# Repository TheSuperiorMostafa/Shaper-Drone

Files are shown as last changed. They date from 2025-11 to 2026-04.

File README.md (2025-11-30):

# ShaperDrone - Autonomous Shape Navigation System

Software repository for the ShaperDrone Engineering Team's autonomous drone project.

## Repository Structure

### Beta 1 (`/beta1`)
Initial implementation with C++ shape detection and navigation modules.
- C++ navigation classes
- Xcode project files
- Drone simulation examples

### Beta 2 (`/beta2`)
Complete Python-based navigation system with full hardware integration.
- MAVLink integration for Flywoo GOKU GN745 V3 AIO flight controller
- Raspberry Pi camera support
- ToF sensor integration
- Autonomous navigation with visual servoing
- Complete setup documentation

## Quick Start

### Beta 2 (Recommended)
```bash
cd beta2
pip3 install opencv-python numpy pymavlink picamera2 VL53L0X
python3 shapeVideo.py
```

See `beta2/SETUP.md` for complete installation and hardware setup instructions.

## Project Overview

The ShaperDrone system enables autonomous navigation through a sequence of shapes. The drone learns a sequence of 3 shapes and then autonomously navigates to each one in order using computer vision and time-of-flight sensing.

## Team

ShaperDrone Engineering Team

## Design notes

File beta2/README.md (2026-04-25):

# ShaperDrone - Autonomous Shape Navigation System

Autonomous navigation system for a sub-250g drone that learns a sequence of shapes and navigates to them in order using computer vision and time-of-flight sensing.

## Hardware

- **Flight Controller:** Flywoo GOKU GN745 V3 AIO (ArduPilot firmware)
- **Computer:** Raspberry Pi Zero 2 W
- **Camera:** Raspberry Pi Camera Module
- **Sensors:** 
  - Time-of-Flight (ToF) sensor (VL53L0X or VL53L1X) for distance measurement
  - Optical Flow sensor (PMW3901, PX4Flow, or similar) for position/velocity estimation

## Features

- **Learning Phase:** Detects and stores 3 shapes in sequence with debouncing
- **Automatic Takeoff:** Automatically takes off to safe altitude after shape learning
- **Gate Navigation:** Flies through shaped gates (not just to them)
- **Navigation Phase:** Autonomously navigates through gates in learned order
- **Visual Servoing:** Uses camera feedback for precise navigation
- **Distance Control:** ToF sensor provides accurate distance measurements
- **Position Hold:** Optical flow sensor enables stable hovering and position hold
- **Velocity Estimation:** Optical flow provides velocity feedback for improved control
- **Motor Kill Switch:** Emergency stop immediately disarms motors (safety requirement)
- **Remote Manual Override:** Network interface for external emergency stop and control
- **Safety Features:** Timeouts, error recovery, automatic RTL

## Installation

See [SETUP.md](SETUP.md) for complete hardware and software setup instructions.

### Quick Start

```bash
# Install dependencies
pip3 install opencv-python numpy pymavlink picamera2 VL53L0X pmw3901

# Run the system
python3 shapeVideo.py
```

Note: For optical flow sensor, install `pmw3901` for PMW3901 sensor or configure for your specific sensor type.

## Controls

### Local Keyboard Controls
- **'q' or ESC:** Quit program
- **'r':** Reset shape order
- **'n':** Manually start navigation
- **'s':** Emergency stop (local)

### Remote Control (Network)
The system includes a remote control server on port 8888 for external manual override:
- **Emergency Stop:** `python3 remote_client.py <pi_ip> emergency_stop`
- **Status Check:** `python3 remote_client.py <pi_ip> status`
- **Telnet:** `telnet <pi_ip> 8888` then type `emergency_stop` or `status`

The remote emergency stop immediately disarms motors (motor kill switch) for safety.

## Project Structure

- `shapeVideo.py` - Main program with camera, shape detection, and navigation
- `navigation.py` - MAVLink flight controller communication (includes takeoff, emergency disarm)
- `shape_navigator.py` - Navigation state machine with gate navigation and visual servoing
- `test_hover.py` - Program testing final prototype integration between navigation and flight controller
- `tof_sensor.py` - Time-of-flight sensor interface
- `optical_flow.py` - Optical flow sensor interface for position/velocity estimation
- `remote_control.py` - Remote control server for manual override and emergency stop
- `remote_client.py` - Client script for remote control commands
- `SETUP.md` - Complete setup guide

## License

[Add your license here]

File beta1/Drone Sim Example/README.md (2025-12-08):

# Drone Simulator Example Script
This is a simple script which shows how a simulated Ardupilot drone can be controlled through a Python script using pymavlink.

## Usage

### Prerequisites
Before you can use this script, you must first install an [Ardupilot Simulator](https://ardupilot.org/dev/docs/simulation-2.html). 
I highly recommend [Mission Planner](https://ardupilot.org/planner/docs/mission-planner-overview.html) for this if you're on a Windows machine, but the [SITL simulator](https://ardupilot.org/dev/docs/sitl-simulator-software-in-the-loop.html#sitl-simulator-software-in-the-loop) is also an option.

You will also need Python 3 and the [pymavlink](https://pypi.org/project/pymavlink/) library.

### Starting the simulator (Mission Planner)
This script uses TCP on port 5764 to communicate with Mission Planner's SITL instance, so you will need to set up Mavlink mirroring before starting the simulator in Mission Planner. See the image below. 
**Note, you will need to click the go/started button here every time you restart mission planner**, otherwise the Python script will be unable to connect.

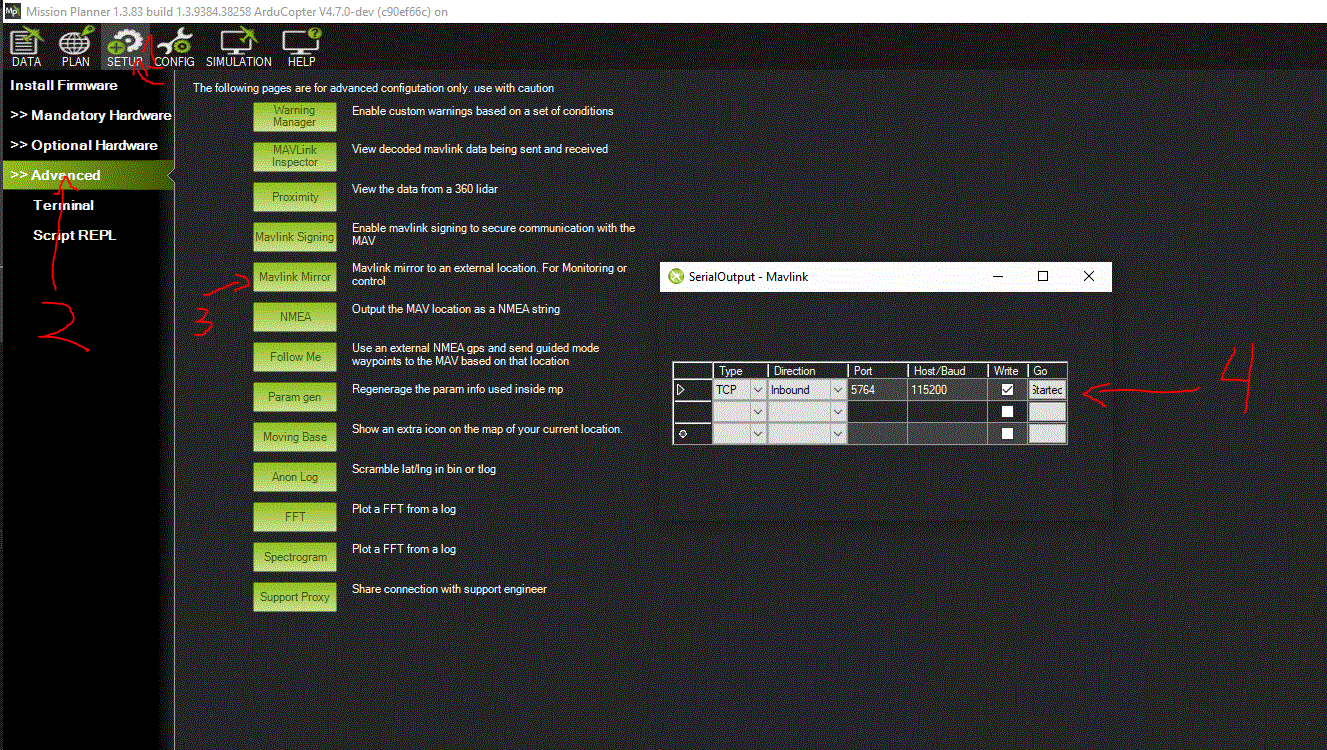
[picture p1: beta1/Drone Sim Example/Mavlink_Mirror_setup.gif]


After this, click on the Simulation tab at the top of the window, and then click the multirotor button at the bottom. The simulation should start.

### Running the script
After the simulation is running, simply run the Python script. The drone should start moving around on its own.

## Useful Guides
Here are some guides that might be useful if you want to familiarize yourself with Ardupilot's simulator, pymavlink, and the Mavlink protocol in general.
- [Mission Planner Simulator user guide](https://www.youtube.com/watch?v=gnSbaGDzrHE): Simple tutorial which is really helpful if you haven't Mission Planner's simulator before.
- [Introduction to pymavlink playlist](https://www.youtube.com/watch?v=kecnaxlUiTY&list=PLy9nLDKxDN68cwdt5EznyAul6R8mUSNou): Good video series to familiarize yourself with using pymavlink.
- [Text based guide on getting started with pymavlink](https://mavlink.io/en/mavgen_python/)

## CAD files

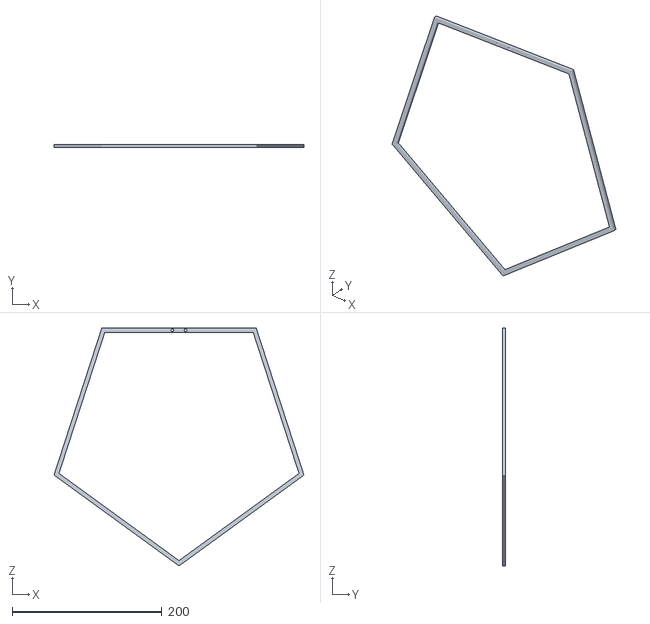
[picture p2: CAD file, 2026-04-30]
3D files/Course/PentagonGate.STL
333.8 x 3.81 x 317.5

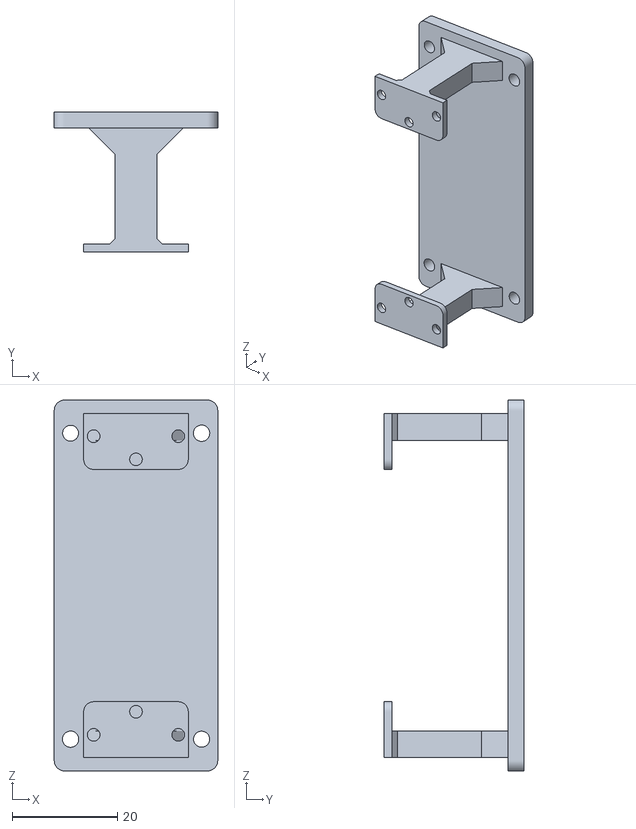
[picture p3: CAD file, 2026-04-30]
3D files/Drone/.STL Files/PI MOUNT 02-08-26.STL
31.0 x 26.5 x 70.4

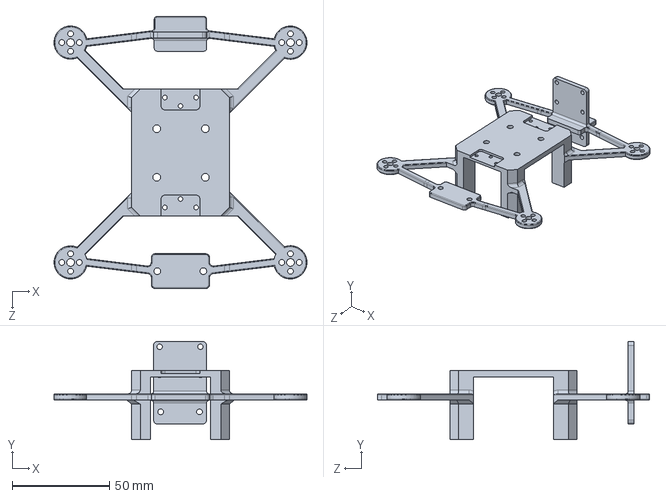
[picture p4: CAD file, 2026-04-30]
3D files/Drone/SolidWorks Files/FRAME RE DO 4-12-26 IN PROG.SLDPRT
130.3 x 50.5 x 140.2 mm

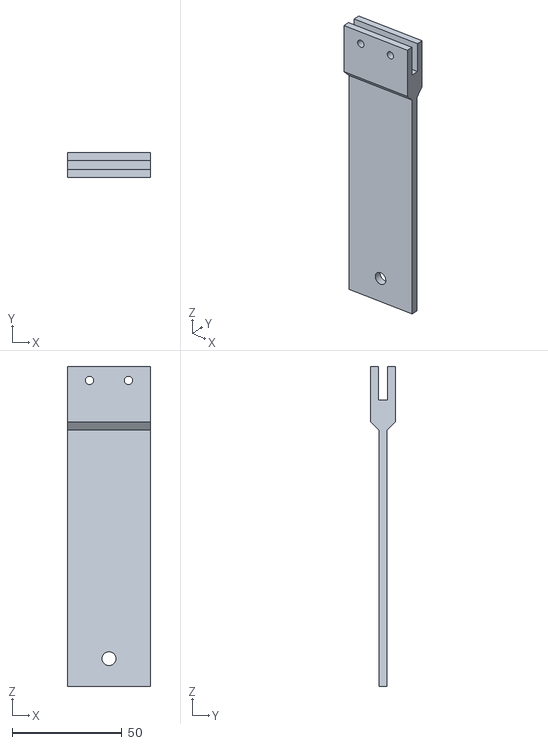
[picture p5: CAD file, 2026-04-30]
3D files/Course/GateToPVCAttachment.STL
38.1 x 11.4 x 146.1

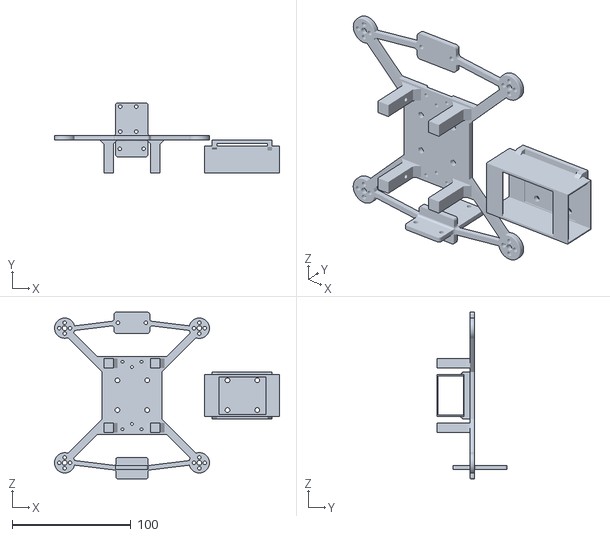
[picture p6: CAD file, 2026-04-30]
3D files/Drone/.STL Files/FRAME + BATTERY STACK 1-28-26.STL
189.2 x 59.2 x 140.2

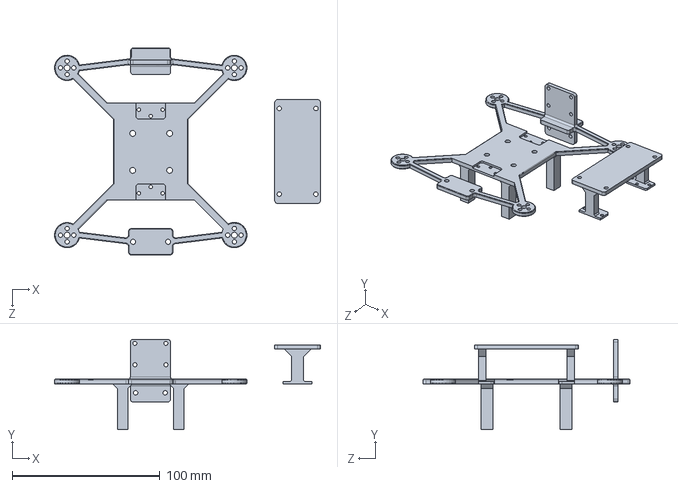
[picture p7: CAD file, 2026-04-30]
3D files/Drone/SolidWorks Files/done and mount 3-30-26.SLDPRT
180.1 x 61.2 x 140.2 mm

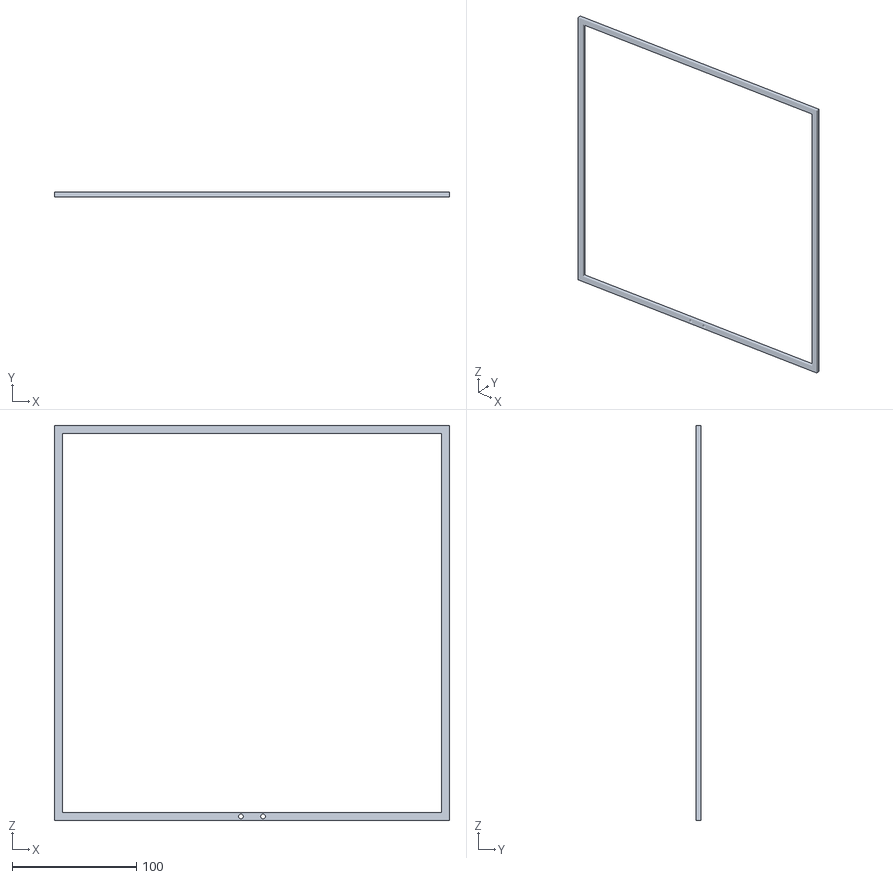
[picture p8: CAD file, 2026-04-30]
3D files/Course/SquareGate.STL
317.5 x 3.81 x 317.5

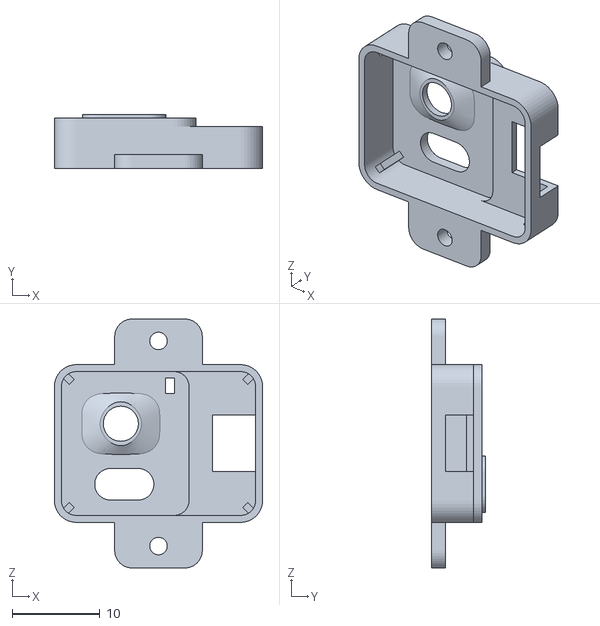
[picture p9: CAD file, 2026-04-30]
3D files/Drone/.STL Files/MTF-02P-V1.2 case.wmounting2.STL
23.8 x 6.20 x 28.4

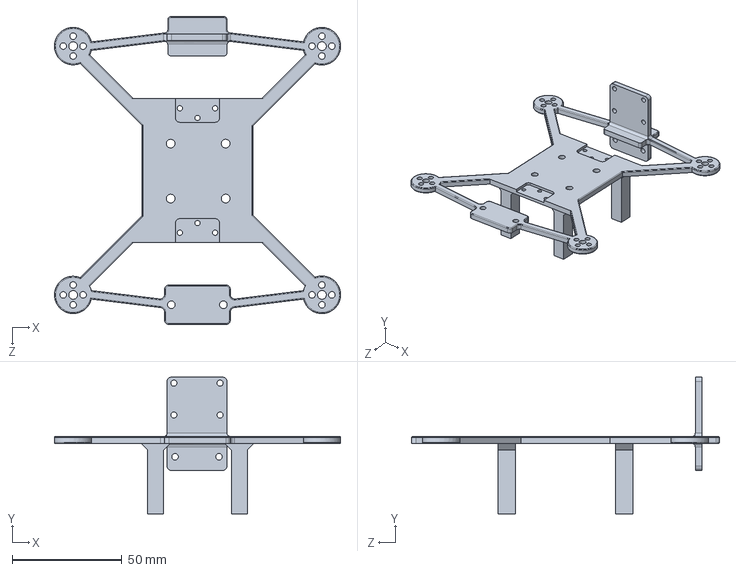
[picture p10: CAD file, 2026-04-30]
3D files/Drone/SolidWorks Files/Frame only 4-2-26.SLDPRT
130.3 x 62.2 x 140.2 mm

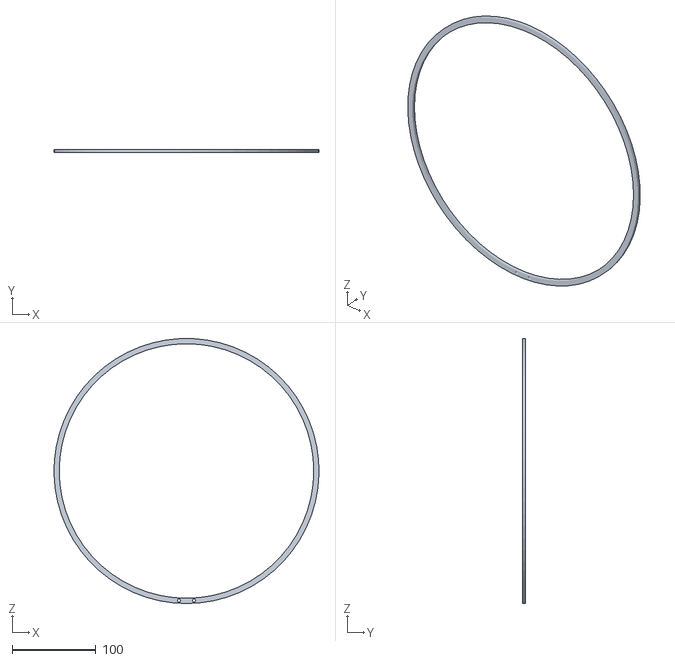
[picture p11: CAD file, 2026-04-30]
3D files/Course/CircleGate.STL
317.4 x 3.81 x 317.5

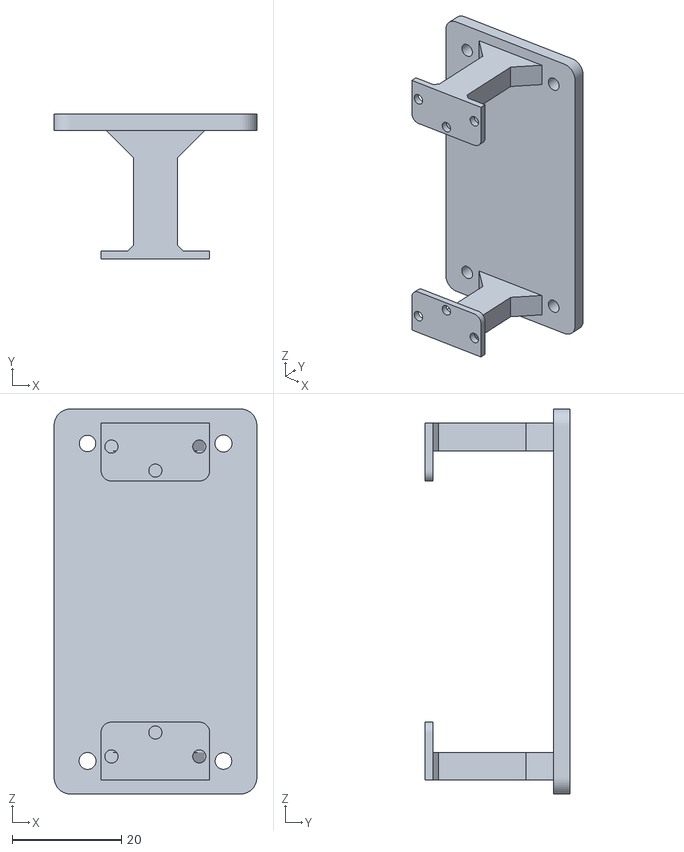
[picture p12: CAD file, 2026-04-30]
3D files/Drone/.STL Files/PI MOUNT v2 STL.STL
37.1 x 26.5 x 70.4

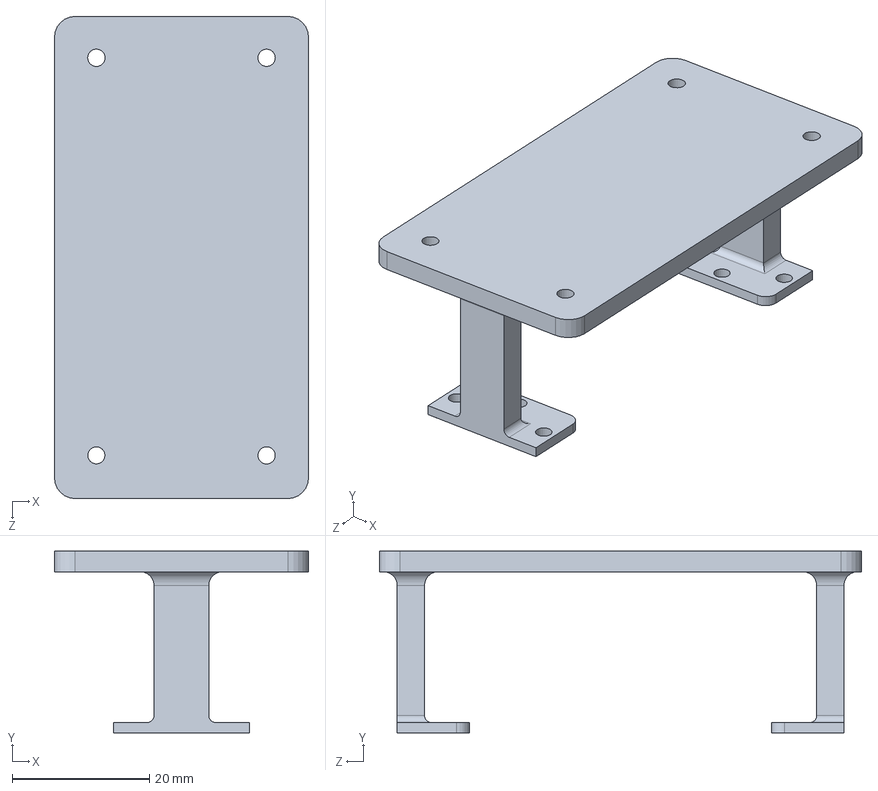
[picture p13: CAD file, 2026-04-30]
3D files/Drone/SolidWorks Files/DRONE FRAME - MODULAR 1-20-26.SLDPRT
37.1 x 26.5 x 70.4 mm

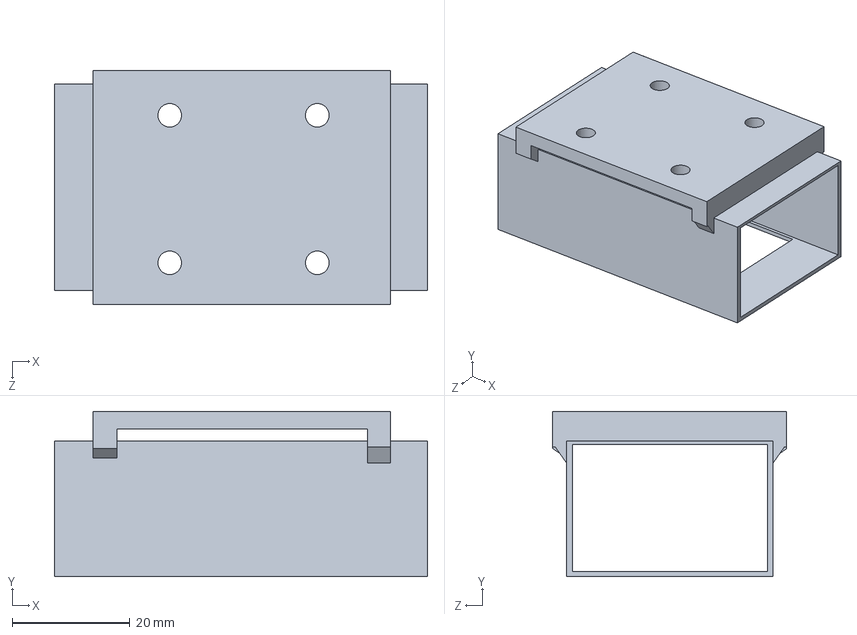
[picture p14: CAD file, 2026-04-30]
3D files/Drone/SolidWorks Files/batt pack 4-2-26.SLDPRT
63.3 x 28.0 x 39.7 mm

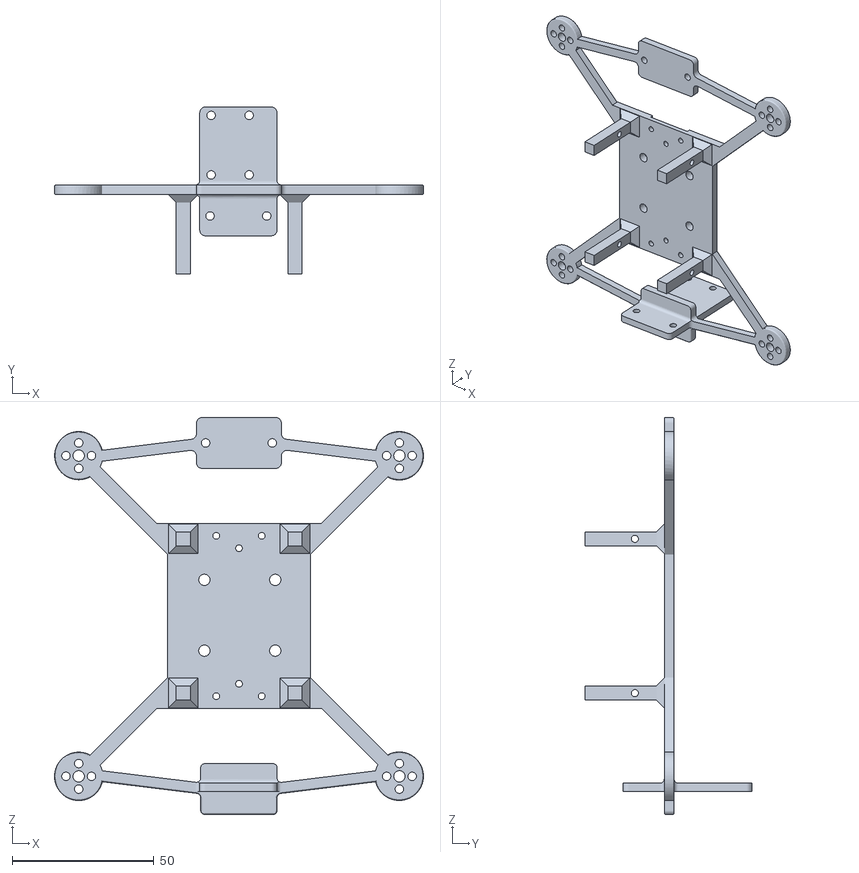
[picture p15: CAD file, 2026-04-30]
3D files/Drone/.STL Files/drone 1-26-26.STL
130.3 x 59.0 x 140.2

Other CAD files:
3D files/Drone/.STL Files/FRAME RE DO 4-12-26.STL
3D files/Drone/SolidWorks Files/PI MOUNT 1-20-26.SLDPRT
3D files/Drone/.STL Files/pi mount 4-2-26.STL
3D files/Drone/SolidWorks Files/FRAME RE DO 4-19-26 IN PROG.SLDPRT
3D files/Drone/.STL Files/DRONE FRAME WITH PI MOUNT - MODULAR 1-21-26.STL
3D files/Drone/.STL Files/DRONE FRAME - MODULAR 1-20-26.STL
3D files/Drone/.STL Files/FRAME RE DO 4-19-26 IN PROG.STL
3D files/Drone/.STL Files/Frame only 4-2-26.STL
3D files/Drone/.STL Files/PI MOUNT 1-20-26.STL
3D files/Drone/.STL Files/batt pack 4-2-26.STL
3D files/Drone/.STL Files/frame only 3-30-26.STL
3D files/Drone/.STL Files/mount only 3-30-26.STL
3D files/Drone/SolidWorks Files/PI MOUNT 02-08-26.SLDDRW

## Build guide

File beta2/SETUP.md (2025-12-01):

# ShaperDrone Setup Guide

## Hardware Components

- **Flight Controller:** Flywoo GOKU GN745 V3 AIO (ArduPilot firmware)
- **Computer:** Raspberry Pi Zero 2 W
- **Camera:** Raspberry Pi Camera Module
- **Sensor:** Time-of-Flight (ToF) sensor (VL53L0X or VL53L1X)

## Hardware Connections

### Flight Controller to Raspberry Pi

1. **UART Connection:**
   - Connect Raspberry Pi GPIO 14 (TX) → FC UART RX
   - Connect Raspberry Pi GPIO 15 (RX) → FC UART TX
   - Connect Ground (GND) → FC GND
   
2. **Power:**
   - Flywoo GOKU GN745 V3 has 5V/2A BEC output
   - Can power Raspberry Pi Zero 2 W (requires ~1A)
   - Connect FC 5V BEC → Pi 5V
   - Connect FC GND → Pi GND

### Camera Connection

- Connect Raspberry Pi Camera Module to Pi's camera connector (CSI)

### ToF Sensor Connections

**Forward-Facing ToF Sensor (for distance to shapes/gates):**
- Connect ToF sensor (VL53L0X) to Raspberry Pi I2C bus:
  - VCC → Pi 3.3V
  - GND → Pi GND
  - SDA → Pi GPIO 2 (I2C SDA)
  - SCL → Pi GPIO 3 (I2C SCL)
- Mount: Point forward, toward shapes/gates
- Purpose: Measures horizontal distance to shapes/gates

**Downward-Facing ToF Sensor (for altitude):**
- Connect second ToF sensor (VL53L0X) to Raspberry Pi I2C bus:
  - VCC → Pi 3.3V
  - GND → Pi GND
  - SDA → Pi GPIO 2 (I2C SDA) - can share same bus
  - SCL → Pi GPIO 3 (I2C SCL) - can share same bus
- **Important:** If using two VL53L0X sensors, you need to change one's I2C address
  - Default VL53L0X address: 0x29
  - Change one sensor's address to 0x30 (or another available address)
  - Or use one VL53L0X and one VL53L1X (they have different default addresses)
- Mount: Point downward, toward ground
- Purpose: Measures altitude (height above ground)

### Optical Flow Sensor Connection (MTF-02B)

- Connect MTF-02B to Raspberry Pi I2C bus:
  - VCC → Pi 3.3V (or 5V, check sensor specifications)
  - GND → Pi GND
  - SDA → Pi GPIO 2 (I2C SDA)
  - SCL → Pi GPIO 3 (I2C SCL)
- Default I2C address: 0x42
- Note: Both ToF and Optical Flow sensors can share the same I2C bus

## ArduPilot Configuration

### 1. Flash ArduPilot Firmware

- Use Mission Planner or QGroundControl to flash ArduPilot firmware
- Select appropriate frame type (Quad, Hex, etc.)

### 2. Configure Serial Port for MAVLink

In Mission Planner or via CLI:

```
SERIALx_PROTOCOL = 2    # MAVLink protocol
SERIALx_BAUD = 57       # 57600 baud
```

Where `x` is the UART port number you're using (typically 1, 2, or 3).

### 3. Enable GUIDED Mode

GUIDED mode should be available by default in ArduPilot. Verify in Mission Planner:
- Flight Modes → GUIDED should be enabled

### 4. Calibration

Complete standard ArduPilot calibration:
- Accelerometer calibration
- Compass calibration
- Radio calibration
- ESC calibration

## Raspberry Pi Setup

### 1. Enable Interfaces

```bash
sudo raspi-config
```

Enable:
- Camera
- I2C
- Serial Port (disable login shell, enable serial port)

### 2. Install Dependencies

```bash
# Update system
sudo apt update && sudo apt upgrade -y

# Install Python packages
pip3 install opencv-python numpy pymavlink picamera2

# For ToF sensor (VL53L0X)
pip3 install VL53L0X

# Or for VL53L1X
pip3 install VL53L1X

# For Optical Flow sensor
# MTF-02B uses smbus (usually pre-installed, or install with: pip3 install smbus2)
# For PMW3901: pip3 install pmw3901
```

### 3. Serial Port Permissions

Add user to dialout group:
```bash
sudo usermod -a -G dialout $USER
```

Log out and back in for changes to take effect.

### 4. Test Serial Connection

```bash
# Check if serial port is available
ls -l /dev/ttyAMA0

# Test connection (optional)
python3 -c "from pymavlink import mavutil; conn = mavutil.mavlink_connection('/dev/ttyAMA0', baud=57600); conn.wait_heartbeat(); print('Connected!')"
```

## Software Configuration

### 1. Configure Sensor Types

Edit `shapeVideo.py`, line ~237-248:
```python
# Forward-facing ToF for distance to shapes/gates
tof_forward = TOFSensor(sensor_type='VL53L0X', i2c_bus=1, address=None)

# Downward-facing ToF for altitude
tof_altitude = TOFSensor(sensor_type='VL53L0X', i2c_bus=1, address=None)
# Note: If both are VL53L0X, configure different I2C addresses
# Or use one VL53L0X and one VL53L1X
```

Edit `shapeVideo.py`, line ~242:
```python
optical_flow = OpticalFlowSensor(sensor_type='MTF-02B', interface='I2C', bus=1, device=0x42)
# MTF-02B is the default. Change to 'PMW3901', 'PX4Flow', or 'simulated' as needed
```

### 2. Adjust Navigation Parameters (Optional)

Edit `shape_navigator.py` to adjust:
- `approach_distance`: Target distance from shapes (default: 2.0m)
- `max_velocity`: Maximum flight velocity (default: 1.0 m/s)
- `search_timeout`: Time to search for each shape (default: 30s)

## Running the System

### 1. Start the Program

```bash
python3 shapeVideo.py
```

### 2. Learning Phase

- Show the drone 3 shapes in sequence
- System will learn the order automatically
- Wait for "ORDER LOCKED" message

### 3. Navigation Phase

- Navigation starts automatically when order is complete
- Or press 'n' to start manually
- Drone will navigate to each shape in sequence

### 4. Controls

- **'q' or ESC:** Quit program
- **'r':** Reset shape order
- **'n':** Manually start navigation
- **'s':** Emergency stop

## Troubleshooting

### Flight Controller Not Connecting

1. Check UART wiring (TX→RX, RX→TX, GND)
2. Verify ArduPilot SERIALx_PROTOCOL = 2
3. Check baud rate matches (57600)
4. Verify serial port permissions
5. Try different UART ports on FC

### Camera Not Working

1. Verify camera is connected to CSI port
2. Enable camera in raspi-config
3. Test with: `libcamera-hello -t 0`

### ToF Sensor Not Detected

1. Check I2C wiring
2. Enable I2C in raspi-config
3. Scan for device: `i2cdetect -y 1`
4. Verify sensor library is installed

### Optical Flow Sensor (MTF-02B) Not Detected

1. **Check I2C wiring:**
   - Verify SDA and SCL connections
   - Ensure proper power (3.3V or 5V depending on sensor)
   - Check ground connection

2. **Enable I2C:**
   - Enable I2C in raspi-config
   - Reboot if necessary

3. **Verify sensor detection:**
   - Scan for device: `i2cdetect -y 1`
   - MTF-02B should appear at address 0x42
   - If not detected, check wiring and power

4. **Check sensor requirements:**
   - Ensure sensor has good lighting
   - Optical flow requires textured surface to work properly
   - Check sensor height (should be 0.5-4m for best results)
   - Sensor should be pointing downward

5. **For other sensors:**
   - **PMW3901 (SPI):** Check SPI wiring, enable SPI, verify library installed
   - **PX4Flow (I2C):** Similar to MTF-02B, check I2C address

### Navigation Issues

1. Ensure shapes are well-lit and high contrast
2. Adjust shape detection thresholds in `shapeVideo.py`
3. Check ToF sensor is providing valid readings
4. Verify flight controller is in GUIDED mode

## Safety Notes

- Always test in a safe, open area
- Start with low velocities
- Have emergency stop ready
- Verify RTL (Return to Launch) works before autonomous flight
- Check battery levels before flight
- Follow local drone regulations

## Specifications Reference

**Flywoo GOKU GN745 V3 AIO:**
- Processor: STM32F745 @ 216MHz
- UART Ports: 7 available
- BEC: 5V/2A (can power Pi Zero 2 W)
- Firmware: ArduPilot compatible

**Raspberry Pi Zero 2 W:**
- Processor: BCM2710A1 (Quad-core 64-bit)
- GPIO UART: /dev/ttyAMA0 (GPIO 14/15)
- I2C: GPIO 2 (SDA), GPIO 3 (SCL)
- Camera: CSI connector

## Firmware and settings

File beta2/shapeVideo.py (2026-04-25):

# shapeVideo.py
# Transitioning from static images to video shape detection

import os
import sys

# Set OpenCV to use a backend that doesn't require X11 (for headless operation)
if 'DISPLAY' not in os.environ:
    os.environ['QT_QPA_PLATFORM'] = 'offscreen'
    # Try to set OpenCV backend to avoid Qt issues
    try:
        os.environ['OPENCV_VIDEOIO_PRIORITY_MSMF'] = '0'
    except:
        pass

import cv2
import time
import numpy as np
import threading
import socket
import struct
from queue import Queue, Empty
from http.server import BaseHTTPRequestHandler, HTTPServer
from navigation import FlightController
from shape_navigator import ShapeNavigator
from remote_control import RemoteControl

try:
    from tof_sensor import TOFSensor
except ModuleNotFoundError:
    class TOFSensor:
        def __init__(self, *args, **kwargs):
            pass
        def is_connected(self):
            return False
        def read_distance(self):
            return None
        def close(self):
            pass

# Vision-only mode: skip flight controller connection (for standalone Pi vision testing)
# Set to True when testing camera/shape detection without FC connected; False when flying.
VISION_ONLY = True

# Check if running headless (no display)
HEADLESS_MODE = 'DISPLAY' not in os.environ
if HEADLESS_MODE:
    print("[INFO] Running in headless mode (no display available)")

# Debug flag for verbose shape-order debounce logging
DEBUG_DEBOUNCE = False

# Stream / processing latency
# - LOW_RES: 320x240 (faster but text/order gets cut off; set False for readable overlays)
# - PROCESS_LATEST_ONLY: skip backlog, always process/display newest frame (reduces delay)
# - PROCESS_EVERY_N_FRAMES: only process every Nth frame (2 = process every 2nd frame, reduces CPU load)
# - ENABLE_HTTP_STREAM: enable HTTP streaming server (disable to reduce CPU/network overhead)
# - ENABLE_UDP_STREAM: enable UDP streaming (lower latency than HTTP)
# - UDP_TARGET_IP: laptop/viewer IP for unicast (e.g. '10.47.232.91'). Set None for broadcast (may not work on eduroam)
LOW_RES_STREAM = False  # 640x480 so full order and labels fit on screen
PROCESS_LATEST_ONLY = True
PROCESS_EVERY_N_FRAMES = 1  # Process every 2nd frame to reduce CPU load
ENABLE_HTTP_STREAM = False  # Set False to disable HTTP streaming and reduce lag
ENABLE_UDP_STREAM = True  # Set True to enable UDP streaming
UDP_TARGET_IP = '10.47.104.64'  # Set to your laptop IP (e.g. '10.47.232.91') for unicast; None = broadcast

# Try to import picamera2 for Raspberry Pi camera
try:
    from picamera2 import Picamera2
    PICAMERA2_AVAILABLE = True
except ImportError:
    PICAMERA2_AVAILABLE = False
    print("[INFO] picamera2 not available, will use OpenCV VideoCapture (USB camera)")


shape_order = []      # will hold up to 3 unique shapes, e.g. ["triangle", "square", "circle"]
order_complete = False

# Debounce state
current_candidate = None
candidate_start_time = None
DEBOUNCE_SECONDS = 1.5  # require ~3s of stable viewing to add a shape to the array

# Global variable to hold the latest frame for streaming
latest_frame = None
frame_lock = threading.Lock()

# Thread-safe queues for frame processing pipeline
# Smaller queues (1-2) reduce latency by preventing frame accumulation
# Frames are dropped if processing can't keep up, ensuring stream shows recent frames
raw_frame_queue = Queue(maxsize=1)  # Raw frames from camera - keep small for low latency
processed_frame_queue = Queue(maxsize=1)  # Processed frames - keep small for low latency
shutdown_event = threading.Event()  # Signal to stop all threads

# Set by stdin listener thread when user types in terminal (headless)
reset_from_stdin_event = threading.Event()
stop_from_stdin_event = threading.Event()

class StreamingHandler(BaseHTTPRequestHandler):
    def do_GET(self):
        if self.path == '/stream':
            self.send_response(200)
            self.send_header('Content-Type', 'multipart/x-mixed-replace; boundary=frame')
            self.end_headers()
            while True:
                with frame_lock:
                    if latest_frame is not None:
                        # Encode frame as JPEG - lower quality (55) for faster encoding and smaller files
                        # This improves stream responsiveness on slower hardware
                        ret, buffer = cv2.imencode('.jpg', latest_frame, [cv2.IMWRITE_JPEG_QUALITY, 55])
                        if ret:
                            frame_bytes = buffer.tobytes()
                            self.wfile.write(b'--frame\r\n')
                            self.send_header('Content-Type', 'image/jpeg')
                            self.send_header('Content-Length', str(len(frame_bytes)))
                            self.end_headers()
                            self.wfile.write(frame_bytes)
                            self.wfile.write(b'\r\n')
                # Reduced sleep for higher frame rate - actual rate limited by camera + processing
                # If processing is slow, we'll show frames as fast as they're available
                time.sleep(0.01)
        elif self.path == '/' or self.path == '/index.html':
            self.send_response(200)
            self.send_header('Content-Type', 'text/html')
            self.end_headers()
            self.wfile.write(b'''
<!DOCTYPE html>
<html>
<head>
    <title>ShaperDrone Camera Stream</title>
    <style>
        body { margin: 0; background: #000; text-align: center; }
        img { max-width: 100%; height: auto; }
    </style>
</head>
<body>
    <img src="/stream" alt="Camera Stream">
</body>
</html>
            ''')
        else:
            self.send_error(404)

def start_streaming_server(port=8080):
    """Start HTTP server for MJPEG streaming"""
    server = HTTPServer(('0.0.0.0', port), StreamingHandler)
    server_thread = threading.Thread(target=server.serve_forever, daemon=True)
    server_thread.start()
    print(f"[STREAM] Camera stream available at http://<pi_ip>:{port}/stream")
    print(f"[STREAM] Web viewer at http://<pi_ip>:{port}/")
    return server

def udp_stream_thread(port=8081, shutdown_event=None, target_ip=None):
    """
    UDP streaming thread - sends JPEG frames over UDP for lower latency.
    target_ip: send to this IP (unicast). If None, use broadcast (may not work on eduroam).
    View with: python udp_viewer.py
    """
    sock = socket.socket(socket.AF_INET, socket.SOCK_DGRAM)
    if target_ip:
        dest = (target_ip, port)
        print(f"[UDP] UDP stream started, sending to {target_ip}:{port} (unicast)")
    else:
        sock.setsockopt(socket.SOL_SOCKET, socket.SO_BROADCAST, 1)
        dest = ('255.255.255.255', port)
        print(f"[UDP] UDP stream started on port {port} (broadcast)")
    print(f"[UDP] Run: python udp_viewer.py (on the viewer machine)")
    
    while not shutdown_event.is_set():
        try:
            with frame_lock:
                if latest_frame is not None:
                    # Encode frame as JPEG (same quality as HTTP stream)
                    ret, buffer = cv2.imencode('.jpg', latest_frame, [cv2.IMWRITE_JPEG_QUALITY, 55])
                    if ret:
                        frame_bytes = buffer.tobytes()
                        frame_size = len(frame_bytes)
                        
                        # Send frame size (4 bytes) + frame data
                        # Format: [4-byte size][JPEG data]
                        packet = struct.pack('>I', frame_size) + frame_bytes
                        
                        try:
                            sock.sendto(packet, dest)
                        except OSError:
                            if not target_ip:
                                try:
                                    sock.sendto(packet, ('127.0.0.1', port))
                                except OSError:
                                    pass
            
            # Small sleep to avoid hammering the network
            time.sleep(0.01)
        except Exception as e:
            print(f"[UDP] Stream error: {e}")
            time.sleep(0.1)
    
    sock.close()
    print("[UDP] UDP stream stopped")

def frame_capture_thread(camera, use_picamera, raw_frame_queue, shutdown_event):
    """
    Thread function to continuously capture frames from camera.
    Runs independently to prevent blocking the main loop.
    """
    print("[THREAD] Frame capture thread started")
    consecutive_errors = 0
    max_errors = 5
    
    while not shutdown_event.is_set():
        try:
            # Read frame from camera
            if use_picamera:
                frame = camera.capture_array()
                # picamera2 returns RGB, convert to BGR for OpenCV
                frame = cv2.cvtColor(frame, cv2.COLOR_RGB2BGR)
                frame = cv2.rotate(frame, cv2.ROTATE_180)
            else:
                ret, frame = camera.read()
                if not ret:
                    consecutive_errors += 1
                    if consecutive_errors >= max_errors:
                        print("[THREAD] Frame capture thread: too many read errors, stopping")
                        break
                    time.sleep(0.1)
                    continue
            
            consecutive_errors = 0
            
            # Put frame in queue for processing (non-blocking, drop old frames if queue is full)
            try:
                raw_frame_queue.put_nowait(frame)
            except:
                # Queue is full, drop oldest frame and add new one
                try:
                    raw_frame_queue.get_nowait()
                    raw_frame_queue.put_nowait(frame)
                except:
                    pass
            
        except Exception as e:
            print(f"[THREAD] Frame capture error: {e}")
            time.sleep(0.1)
    
    print("[THREAD] Frame capture thread stopped")

def frame_processing_thread(raw_frame_queue, processed_frame_queue, tof_sensor, shutdown_event, min_contour_area=800):
    """
    Thread function to process frames for shape detection.
    Runs independently to prevent blocking frame capture or navigation.
    min_contour_area: minimum contour area (e.g. 200 for 320x240, 800 for 640x480).
    """
    print("[THREAD] Frame processing thread started")
    
    # Frame skipping counter for PROCESS_EVERY_N_FRAMES
    frame_counter = 0
    last_result = None  # Store last processed result to reuse when skipping frames
    
    while not shutdown_event.is_set():
        try:
            # Get frame(s) from queue
            frame = None
            if PROCESS_LATEST_ONLY:
                # Drain queue and keep only the latest frame (reduces delay from backlog)
                while True:
                    try:
                        frame = raw_frame_queue.get_nowait()
                    except Empty:
                        break
            if frame is None:
                try:
                    frame = raw_frame_queue.get(timeout=0.05)
                except Empty:
                    continue
            
            # Frame skipping: only process every Nth frame to reduce CPU load
            frame_counter += 1
            if frame_counter % PROCESS_EVERY_N_FRAMES != 0:
                # Skip processing - reuse last result if available, or pass raw frame
                if last_result is not None:
                    # Reuse last processed result (labels/positions stay same, but update frame for visual continuity)
                    result = last_result.copy()
                    result['frame'] = frame  # Use current raw frame so stream stays responsive
                    try:
                        processed_frame_queue.put_nowait(result)
                    except:
                        try:
                            processed_frame_queue.get_nowait()
                            processed_frame_queue.put_nowait(result)
                        except:
                            pass
                continue
            
            # Read ToF sensor distance
            distance = tof_sensor.read_distance()
            
            # Process frame for shape detection
            annotated, frame_labels, shape_positions = process_frame(frame, min_contour_area)
            
            # Store result for reuse when skipping frames
            last_result = {
                'frame': annotated,
                'labels': frame_labels,
                'positions': shape_positions,
                'distance': distance
            }
            
            # Put processed result in queue
            try:
                processed_frame_queue.put_nowait(last_result)
            except:
                # Queue is full, drop oldest result and add new one
                try:
                    processed_frame_queue.get_nowait()
                    processed_frame_queue.put_nowait(last_result)
                except:
                    pass
                    
        except Exception as e:
            print(f"[THREAD] Frame processing error: {e}")
            time.sleep(0.01)
    
    print("[THREAD] Frame processing thread stopped")

def stdin_listener_thread(shutdown_evt, reset_evt, stop_evt):
    """
    Read lines from terminal stdin; set reset_evt for 'r'/'reset', stop_evt for 's'/'stop'.
    Allows reset and emergency stop from the SSH terminal when running headless.
    """
    while not shutdown_evt.is_set():
        try:
            line = sys.stdin.readline()
            if not line:
                break
            s = line.strip().lower()
            if s in ('r', 'reset'):
                reset_evt.set()
            elif s in ('s', 'stop'):
                stop_evt.set()
        except Exception:
            break
    print("[THREAD] Stdin listener stopped")

def classify(contour, min_area=800):
    area = cv2.contourArea(contour)

    if area < min_area:
        return None

    perim = cv2.arcLength(contour, True)
    if perim == 0:
        return None

    circularity = 4.0 * np.pi * area / (perim * perim)

    # For checking how well the circle fills its minimum enclosing circle
    (_, _),radius = cv2.minEnclosingCircle(contour) # minEnclosingCircle returns ((cx,cy), radius)
    circle_area = np.pi * radius * radius
    fill_ratio = area / circle_area if circle_area > 0 else 0

    eps = 0.01 * perim
    approx = cv2.approxPolyDP(contour, eps, True)
    n = len(approx)

    # --------------- Circle test first -------------------------------
    # For a real disk, both circularity and fill_ratio should be high.
    # (These thresholds are intentionally not super strict to handle low-contrast edges.)
    if n>= 7 and circularity > 0.75 and fill_ratio > 0.7:
        return "Circle"
    
    # -------------- Polygon approximation for non-circles --------------
    if n == 3:
        return "Triangle"
    elif n == 4:
        _, _, w, h = cv2.boundingRect(approx)
        ar = w / float(h)
        if 0.9 < ar < 1.1:
            return "Square"
    elif n == 5:
        # For a "real" pentagon we expect something not crazy skinny (closer to a square)
        # Aspect ratio (ar) and circularity checks added so long skinny shapes aren't detected
        _, _, w, h = cv2.boundingRect(approx)
        ar = w / float(h)
        if 0.7 < ar < 1.3 and circularity > 0.3:
            return "Pentagon"
        else:
            return None
    elif n == 6:
        # Same goes for a hexagon
        _, _, w, h = cv2.boundingRect(approx)
        ar = w / float(h)
        if 0.7 < ar < 1.3 and circularity > 0.3:
            return "Hexagon"
        else:
            return None
    else: 
        return None


def process_frame(image, min_contour_area=800):
    """
    Takes a BGR image, returns:
      - annotated_image
      - list of labels detected in this frame (e.g. ["Triangle", "Circle"])
      - dict mapping shape labels to (x, y, area) tuples for position tracking
    min_contour_area: minimum contour area (scale down for low-res, e.g. 200 for 320x240)
    """
    h, w = image.shape[:2]
    max_area = 0.9 * h * w  # treat anything this big as the outer frame

    gray = cv2.cvtColor(image, cv2.COLOR_BGR2GRAY)

    # Smooth small noise / shadows - reduced kernel size (3x3) for faster processing
    blur = cv2.GaussianBlur(gray, (3, 3), 0)

    # Let Otsu pick the threshold instead of hard-coding 220
    _, th = cv2.threshold(
    blur, 0, 255,
    cv2.THRESH_BINARY_INV + cv2.THRESH_OTSU
    )

    contours, _ = cv2.findContours(th, cv2.RETR_TREE, cv2.CHAIN_APPROX_SIMPLE)

    detected_labels = []
    shape_positions = {}  # Maps shape label to (x, y, area)
    annotated = image.copy()

    for c in contours:
        area = cv2.contourArea(c)
        # skip tiny specks and giant outer border
        if area < min_contour_area or area > max_area:
            continue

        label = classify(c, min_contour_area)
        if not label:
            continue

        # Calculate centroid
        M = cv2.moments(c)
        if M["m00"] != 0:
            cx = int(M["m10"] / M["m00"])
            cy = int(M["m01"] / M["m00"])
            
            # Store position (use largest area if multiple detections of same shape)
            if label not in shape_positions or area > shape_positions[label][2]:
                shape_positions[label] = (cx, cy, area)
            
            # Only add each label once per frame to reduce noise
            if label not in detected_labels:
                detected_labels.append(label)

            cv2.drawContours(annotated, [c], -1, (0, 0, 0), 3)
            cv2.putText(annotated, label, (cx - 40, cy),
                        cv2.FONT_HERSHEY_DUPLEX, 0.7, (0, 0, 0), 2)

    return annotated, detected_labels, shape_positions

def identify_order(detected_shapes_frame):
    """
    detected_shapes_frame: list of labels seen this frame, e.g. ["Triangle", "Circle"]

    Debounce logic:
      - Only consider shapes that are NOT already in shape_order.
      - If we see the same candidate shape continuously for DEBOUNCE_SECONDS,
        we accept it and append to shape_order.
    """
    global shape_order, order_complete
    global current_candidate, candidate_start_time

    if order_complete:
        return shape_order

    # No shapes in this frame → we "lost" the target; reset candidate
    # Use grace period: with frame skipping, empty labels can be stale - don't reset on first empty
    if not detected_shapes_frame:
        if not hasattr(identify_order, 'empty_count'):
            identify_order.empty_count = 0
        identify_order.empty_count += 1
        if identify_order.empty_count >= 2:  # Require 2 consecutive empty to reset
            if current_candidate is not None:
                if DEBUG_DEBOUNCE:
                    print("[DEBUG] Lost sight of candidate, resetting debounce.")
            current_candidate = None
            candidate_start_time = None
        return shape_order
    identify_order.empty_count = 0  # Reset when we see shapes

    # Pick a candidate shape from this frame:
    # Prefer shapes that are not already in shape_order
    candidate = None
    for s in detected_shapes_frame:
        if s not in shape_order:
            candidate = s
            break

    # If everything we see is already in shape_order, nothing new to learn
    if candidate is None:
        return shape_order

    now = time.time()

    # New candidate shape → start (or restart) the debounce timer
    if candidate != current_candidate:
        current_candidate = candidate
        candidate_start_time = now
        if DEBUG_DEBOUNCE:
            print(f"[DEBUG] New candidate '{current_candidate}', starting debounce timer.")
        return shape_order

    # Same candidate as last frame → check how long we've seen it
    if candidate_start_time is not None:
        elapsed = now - candidate_start_time
        if elapsed >= DEBOUNCE_SECONDS:
            # Debounced: accept this shape into the order
            shape_order.append(current_candidate)
            if DEBUG_DEBOUNCE:
                print(f"[DEBUG] Debounced + accepted '{current_candidate}'. Order = {shape_order}")

            current_candidate = None
            candidate_start_time = None

            if len(shape_order) == 3:
                order_complete = True
                if DEBUG_DEBOUNCE:
                    print(f"[DEBUG] Final order locked in: {shape_order}")

    return shape_order
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

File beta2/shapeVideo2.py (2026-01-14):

# Transitioning from static images to video shape detection

import cv2
import time
import numpy as np
# from pymavlink import mavutil  # commented out for now
import sys


shape_order = []      # will hold up to 3 unique shapes, e.g. ["triangle", "square", "circle"]
order_complete = False

# Debounce state
current_candidate = None
candidate_start_time = None
DEBOUNCE_SECONDS = 1.5  # require ~1.5s of stable viewing to add a shape to the array

STATE_ORDER = "ORDER"
STATE_IN_FLIGHT = "IN_FLIGHT"
state = STATE_ORDER

POST_ORDER_HOLD_SECONDS = 5.0
order_locked_time = None  # when order_complete first became True

last_order_polarity = None

def classify(contour):
    area = cv2.contourArea(contour)

    if area < 800:
        return None

    perim = cv2.arcLength(contour, True)
    if perim == 0:
        return None

    circularity = 4.0 * np.pi * area / (perim * perim)

    # For checking how well the circle fills its minimum enclosing circle
    (_, _),radius = cv2.minEnclosingCircle(contour) # minEnclosingCircle returns ((cx,cy), radius)
    circle_area = np.pi * radius * radius
    fill_ratio = area / circle_area if circle_area > 0 else 0

    eps = 0.01 * perim
    approx = cv2.approxPolyDP(contour, eps, True)
    n = len(approx)

    # --------------- Circle test first -------------------------------
    # For a real disk, both circularity and fill_ratio should be high.
    # (These thresholds are intentionally not super strict to handle low-contrast edges.)
    if n>= 7 and circularity > 0.75 and fill_ratio > 0.7:
        return "Circle"
    
    # -------------- Polygon approximation for non-circles --------------
    if n == 3:
        return "Triangle"
    elif n == 4:
        _, _, w, h = cv2.boundingRect(approx)
        ar = w / float(h)
        return "Square" if 0.9 < ar < 1.1 else "Rectangle"
    elif n == 5:
        # For a "real" pentagon we expect something not crazy skinny (closer to a square)
        # Aspect ratio (ar) and circularity checks added so long skinny shapes aren't detected
        _, _, w, h = cv2.boundingRect(approx)
        ar = w / float(h)
        if 0.7 < ar < 1.3 and circularity > 0.3:
            return "Pentagon"
        else:
            return None
    elif n == 6:
        # Same goes for a hexagon
        _, _, w, h = cv2.boundingRect(approx)
        ar = w / float(h)
        if 0.7 < ar < 1.3 and circularity > 0.3:
            return "Hexagon"
        else:
            return None
    else: 
        return None

def threshold_auto_polarity(gray):
    blur = cv2.GaussianBlur(gray, (5, 5), 0)

    _, th_bin = cv2.threshold(blur, 0, 255, cv2.THRESH_BINARY + cv2.THRESH_OTSU)
    _, th_inv = cv2.threshold(blur, 0, 255, cv2.THRESH_BINARY_INV + cv2.THRESH_OTSU)

    # light cleanup on both
    kernel = np.ones((5,5), np.uint8)
    th_bin = cv2.morphologyEx(th_bin, cv2.MORPH_OPEN, kernel, iterations=1)
    th_inv = cv2.morphologyEx(th_inv, cv2.MORPH_OPEN, kernel, iterations=1)

    return th_bin, th_inv


def process_frame(image):
    """
    Takes a BGR image, returns:
      - annotated_image
      - list of labels detected in this frame (e.g. ["Triangle", "Circle"])
    """

    global last_order_polarity
    
    h, w = image.shape[:2]
    max_area = 0.9 * h * w  # treat anything this big as the outer frame

    gray = cv2.cvtColor(image, cv2.COLOR_BGR2GRAY)

    # --- pick best threshold polarity (BIN vs INV) ---
    th_bin, th_inv = threshold_auto_polarity(gray)

    def score_mask(th):
        contours, _ = cv2.findContours(th, cv2.RETR_EXTERNAL, cv2.CHAIN_APPROX_SIMPLE)
        best = 0.0
        for c in contours:
            area = cv2.contourArea(c)
            if area < 800 or area > max_area:
                continue
            perim = cv2.arcLength(c, True)
            if perim <= 0:
                continue
            circ = 4.0 * np.pi * area / (perim * perim)
            # Prefer compact blobs; cap circularity at 1
            best = max(best, area * min(circ, 1.0))
        return best

    score_bin = score_mask(th_bin)
    score_inv = score_mask(th_inv)
  
    th = th_inv if score_inv > score_bin else th_bin
    cv2.imshow("th_order", th)

    pol = "INV" if score_inv > score_bin else "BIN"
    if pol != last_order_polarity:
        print(f"[ORDER] Polarity switched -> {pol} (bin={score_bin:.1f}, inv={score_inv:.1f})")
        last_order_polarity = pol

    # --- contours from chosen mask ---
    contours, _ = cv2.findContours(th, cv2.RETR_EXTERNAL, cv2.CHAIN_APPROX_SIMPLE)

    detected_labels = []
    annotated = image.copy()

    for c in contours:
        area = cv2.contourArea(c)
        if area < 800 or area > max_area:
            continue

        label = classify(c)
        if not label:
            continue

        if label not in detected_labels:
            detected_labels.append(label)

        cv2.drawContours(annotated, [c], -1, (0, 0, 0), 3)

        M = cv2.moments(c)
        if M["m00"] != 0:
            cx = int(M["m10"] / M["m00"])
            cy = int(M["m01"] / M["m00"])
            cv2.putText(
                annotated, label, (cx - 40, cy),
                cv2.FONT_HERSHEY_DUPLEX, 0.7, (0, 0, 0), 2
            )

    return annotated, detected_labels
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

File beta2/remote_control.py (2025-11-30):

"""
Remote control interface for manual override and emergency stop.
Provides network interface for external control commands.
"""

import socket
import threading
import json
import time

class RemoteControl:
    """Network interface for remote manual override commands."""
    
    def __init__(self, port=8888, host='0.0.0.0'):
        """
        Initialize remote control server.
        
        Args:
            port: TCP port to listen on (default: 8888)
            host: Host address to bind to (default: '0.0.0.0' for all interfaces)
        """
        self.port = port
        self.host = host
        self.socket = None
        self.server_thread = None
        self.running = False
        self.callbacks = {
            'emergency_stop': None,
            'manual_override': None,
            'status_request': None
        }
    
    def set_emergency_stop_callback(self, callback):
        """Set callback function for emergency stop command."""
        self.callbacks['emergency_stop'] = callback
    
    def set_manual_override_callback(self, callback):
        """Set callback function for manual override commands."""
        self.callbacks['manual_override'] = callback
    
    def set_status_request_callback(self, callback):
        """Set callback function for status requests."""
        self.callbacks['status_request'] = callback
    
    def start_server(self):
        """Start the remote control server in a separate thread."""
        if self.running:
            print("[REMOTE] Server already running")
            return
        
        self.running = True
        self.server_thread = threading.Thread(target=self._server_loop, daemon=True)
        self.server_thread.start()
        print(f"[REMOTE] Remote control server started on {self.host}:{self.port}")
        print("[REMOTE] Commands: 'emergency_stop', 'status', or JSON commands")
    
    def stop_server(self):
        """Stop the remote control server."""
        self.running = False
        if self.socket:
            try:
                self.socket.close()
            except:
                pass
        print("[REMOTE] Remote control server stopped")
    
    def _server_loop(self):
        """Main server loop - handles incoming connections."""
        try:
            self.socket = socket.socket(socket.AF_INET, socket.SOCK_STREAM)
            self.socket.setsockopt(socket.SOL_SOCKET, socket.SO_REUSEADDR, 1)
            self.socket.bind((self.host, self.port))
            self.socket.listen(5)
            self.socket.settimeout(1.0)  # Allow periodic checking of self.running
            
            while self.running:
                try:
                    client_socket, address = self.socket.accept()
                    print(f"[REMOTE] Connection from {address}")
                    # Handle client in a separate thread
                    client_thread = threading.Thread(
                        target=self._handle_client,
                        args=(client_socket, address),
                        daemon=True
                    )
                    client_thread.start()
                except socket.timeout:
                    continue
                except Exception as e:
                    if self.running:
                        print(f"[REMOTE] Error accepting connection: {e}")
        except Exception as e:
            if self.running:
                print(f"[REMOTE] Server error: {e}")
    
    def _handle_client(self, client_socket, address):
        """Handle a single client connection."""
        try:
            client_socket.settimeout(5.0)
            while self.running:
                data = client_socket.recv(1024).decode('utf-8')
                if not data:
                    break
                
                data = data.strip()
                response = self._process_command(data)
                
                if response:
                    client_socket.sendall((response + '\n').encode('utf-8'))
                
        except socket.timeout:
            pass
        except Exception as e:
            print(f"[REMOTE] Error handling client {address}: {e}")
        finally:
            client_socket.close()
            print(f"[REMOTE] Client {address} disconnected")
    
    def _process_command(self, command):
        """Process incoming command and return response."""
        command = command.strip().lower()
        
        # Emergency stop command
        if command == 'emergency_stop' or command == 'kill' or command == 'stop':
            print("[REMOTE] Emergency stop command received!")
            if self.callbacks['emergency_stop']:
                self.callbacks['emergency_stop']()
            return "OK: Emergency stop activated"
        
        # Status request
        elif command == 'status' or command == 'info':
            if self.callbacks['status_request']:
                status = self.callbacks['status_request']()
                return json.dumps(status)
            return "OK: Status requested"
        
        # JSON command (for future expansion)
        elif command.startswith('{'):
            try:
                cmd_data = json.loads(command)
                cmd_type = cmd_data.get('command', '').lower()
                
                if cmd_type == 'manual_override':
                    if self.callbacks['manual_override']:
                        self.callbacks['manual_override'](cmd_data.get('data', {}))
                    return "OK: Manual override command processed"
                else:
                    return f"ERROR: Unknown command type: {cmd_type}"
            except json.JSONDecodeError:
                return "ERROR: Invalid JSON"
        
        else:
            return f"ERROR: Unknown command: {command}. Use 'emergency_stop', 'status', or JSON"
    
    def send_command(self, host, port, command):
        """
        Send a command to a remote control server (client mode).
        
        Args:
            host: Server hostname or IP
            port: Server port
            command: Command string to send
        
        Returns:
            str: Server response
        """
        try:
            sock = socket.socket(socket.AF_INET, socket.SOCK_STREAM)
            sock.settimeout(5.0)
            sock.connect((host, port))
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

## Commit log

2025-11-30 Initial commit: ShaperDrone autonomous navigation system
    - MAVLink integration for Flywoo GOKU GN745 V3 AIO flight controller
    - Shape detection and learning system
    - Autonomous navigation with visual servoing
    - ToF sensor integration for distance measurement
    - Raspberry Pi camera support
    - Safety features and error handling
    - Complete setup documentation
    [navigation.py, shapeVideo.py, shape_navigator.py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]
2025-11-30 Add Beta 2: Complete navigation system with MAVLink, ToF sensor, and Pi camera integration
2025-11-30 Add prototype features: automatic takeoff, gate navigation, motor kill switch, remote control
    - Automatic takeoff sequence after shape learning
    - Gate navigation: flies through gates (not just to them)
    - Motor kill switch: emergency stop immediately disarms motors
    - Remote manual override: TCP server on port 8888 for external control
    - Remote client script for emergency stop and status commands
    - Updated navigation state machine with takeoff and gate-passing states
    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
2025-12-01 Add optical flow sensor integration for position hold and velocity estimation
    - Created optical_flow.py module supporting PMW3901, PX4Flow, and simulated modes
    - Integrated optical flow sensor into navigation system
    - Added position hold capability using optical flow during search/hover
    - Real-time velocity and position estimation from optical flow
    - Updated documentation with optical flow sensor setup instructions
    - Enhanced position stability during gate navigation
    [optical_flow.py, shapeVideo.py, shape_navigator.py]
2025-12-01 Update sensor configuration: VL53L0X ToF and MTF-02B Optical Flow
    - Set MTF-02B as default optical flow sensor (I2C interface)
    - Added MTF-02B I2C protocol implementation
    - Updated default sensor types in shapeVideo.py
    - Updated documentation with MTF-02B wiring and configuration
    - Both sensors use I2C and can share the same bus
2025-12-01 Add support for dual ToF sensors: forward-facing and altitude
    - Forward-facing ToF sensor for distance to shapes/gates
    - Downward-facing ToF sensor for altitude measurement
    - Updated navigation to use forward distance for shape approach
    - Altitude tracking for height control
    - Updated documentation with dual sensor setup instructions
    - Note: Two VL53L0X sensors require different I2C addresses
2025-12-08 Updated navigation class
    - Removed send_position_command which relied on GPS lat/long, replaced it with send_absolute_position_command and send_relative_position_command, which send the drone to points relative to the local EKF origin and current drone position respectively
    - update_vehicle_state will now get the drone's position relative to the EKF origin rather than a GPS lat/long
    - Added send_absolute_rotation_command, and send_relative_rotation_command, which let the drone change its yaw (both heading and yaw rate)
    - Added set_EKF_origin, which lets the drone set its EKF origin manually. because we do not have GPS, this function must be run when the drone first starts up.
    - fixed missing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
    [navigation.py]
2026-01-27 Fixed several bugs with FlightController class
    Fixed several bugs that were found using Ardupilots SITL simulator
    [navigation.py]
2026-04-30 Added 3D design files from Teams folder
    [CircleGate.STL, DRONE FRAME WITH PI MOUNT - MODULAR 1-21-26.STL, DRONE FRAME - MODULAR 1-20-26.SLDPRT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]
